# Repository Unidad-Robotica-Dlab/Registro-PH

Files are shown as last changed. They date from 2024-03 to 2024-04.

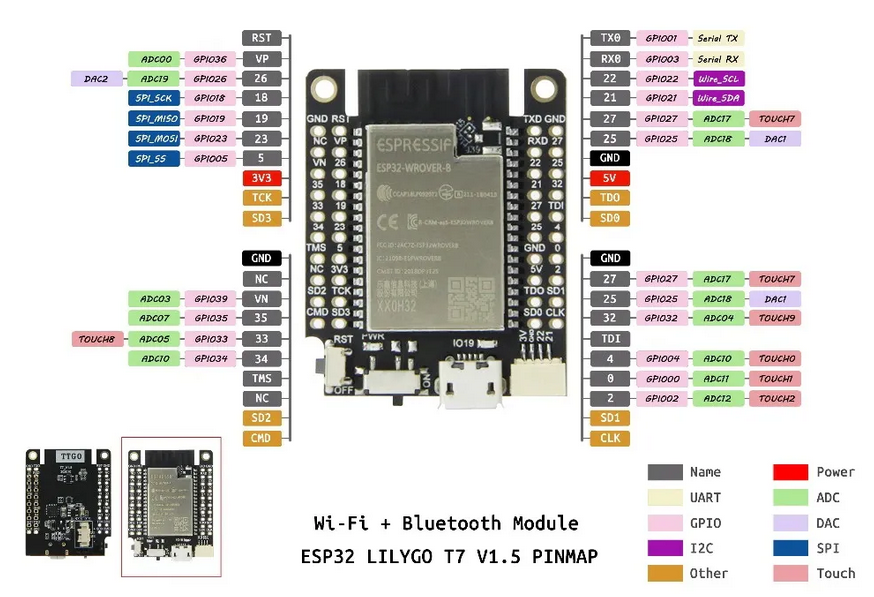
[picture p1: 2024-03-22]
Materiales/ESP32 lilygo 1.5 pinout.png

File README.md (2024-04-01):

# Proyecto: Registro-PH
## Solicitante: Simon Beard
## Contacto:sbeard@cienciavida.org 
### Laboratorio: Microbial Ecophysiology Lab Fundación Ciencia y Vida

#### Introducción:
La Maquina ElectroLab FerMac 200 es capaz de controlar el pH de una solución de forma mecánica y cuenta con un display que muestra el pH en tiempo real.

#### Requerimientos:
- Registrar el pH mediante un ESP32 y guardar los datos en una base de datos.
- Fecha de solicitud: 06/03/2024
	- Almacenar los datos de la lectura en la base de datos del ordenador.
	- Duración total de la fermentación: 4 días.
	- Tasa de muestreo por determinar.
	- Implementación de un menú interactivo.

#### Metodología:
- Leer el voltaje de salida del amplificador operacional (amplificador operacional) en la placa electrónica de la máquina, aislar el circuito mediante la adición de otro amplificador operacional en modo diferencial y leer nuevamente el voltaje de salida mediante un ESP32.
  
  1) Establecer el rango de operación en voltaje del sensor de pH.
  2) Implementar un sistema de acoplamiento con amplificador operacional.
  3) Registrar el voltaje como lectura analógica en ESP32.
  4) Almacenar los datos de la lectura en la base de datos del ordenador.

#### Software:
- [Firmware-E_RPH_v0-1](https://github.com/Unidad-Robotica-Dlab/Registro-PH/blob/main/Software/Firmware-E_RPH_v0-1/Firmware-E_RPH_v0-1.ino):
	- El ESP32 realiza la lectura del voltaje y calcula un promedio de 10 subpromedios, donde cada subpromedio es el promedio de 10 lecturas.
	- Imprime el valor de pH calculado a partir de una ecuación lineal.
- [Firmware-E_RPH_v0-2](https://github.com/Unidad-Robotica-Dlab/Registro-PH/blob/main/Software/Firmware-E_RPH_v0-2/Firmware-E_RPH_v0-2.ino):
	- Agregada la comunicacion serial con Python.
- [Software_RPH_v0-2](https://github.com/Unidad-Robotica-Dlab/Registro-PH/blob/main/Software/Software_RPH_v0-2.ipynb):
	- Interfaz de usuario con Menu para guardar los datos en un csv:
 		-  Variable: Tiempo de grabacion
   		-  Variable: Tiempo entre lecturas
- [Firmware-E_RPH_v1-0](https://github.com/Unidad-Robotica-Dlab/Registro-PH/blob/main/Software/Firmware_E_RPH_v1-0/Firmware_E_RPH_v1-0/Firmware_E_RPH_v1-0.ino)
	- Firmware 100% operativo
- [Software_RPH_v1-0](https://github.com/Unidad-Robotica-Dlab/Registro-PH/blob/main/Software/Software_RPH_v1-0.py):
	- Software 100% operativo
 		-  [Manual Tecnico del Software](https://github.com/Unidad-Robotica-Dlab/Registro-PH/blob/main/Software/Software_manual-tecnico.txt) 
   		-  [Descripción del Software](https://github.com/Unidad-Robotica-Dlab/Registro-PH/blob/main/Software/Software_descripcion.txt)

#### Notas:
- [12/02/24]
	- La máquina pH se encuentra en Robótica.
- [16/02/24]:
	- La máquina pH ha sido desarmada y se dispone de todos los implementos necesarios para medir el pH. Se han obtenido tres valores de pH diferentes: 1.68pH, 4pH y 10.1pH.
- [19/02/24]:
	- Se ha medido el voltaje de salida en el amplificador operacional de la máquina y se ha implementado un divisor de tensión.
	- Para 1.68pH, el voltaje de salida es de 17V; para 10.1pH, es de 11.1V (Voltaje de salida del amplificador operacional de la máquina [modelo: OPA602AP]).
	- Después del divisor de tensión, para 1.68pH, el voltaje es de 2.83V; para 10.1pH, es de 1.85V.
	- Los valores leídos analógicamente son 402 para 1.68pH y 261 para 10.1pH.
	- Ecuación de la recta: y = -0.0597x + 25.685.
- [21/02/24]:
	- Se ha eliminado el divisor de tensión y se ha agregado un amplificador operacional en modo diferencial para aislar los circuitos.
	- Para 1.68pH, el voltaje de salida es de 17V; para 10.1pH, es de 11.1V (Voltaje de salida del amplificador operacional de la máquina [modelo: OPA602AP]).
	- Después de agregar el amplificador operacional, para 1.68pH, el voltaje es de 2.16V; para 10.1pH, es de 1.58V.
	- Los valores leídos analógicamente son 302 para 1.68pH y 227 para 10.1pH.
	- Ecuación de la recta: y = -0.11226x + 35.58453.

- [11/03/24]:
	- Cotización y diseño del soporte del dispositivo en Inkscape.

- [19/03/24]:
	- Perillas AKHALI y ACID regulan el set point del rango de pH a leer. Para mover el setpoint se deja el encoder en SET
	- Perillas SLOPE and CAL regulan la pendiente y el intercepto. SLOPE se usa para pH 4 y  CAL para pH 7
 	- Verificar si al mover SLOPE and CAL modifica el valor del voltaje
    
- [21/03/24]:
	- Agregar menu de calibracion. Donde se calibre la maquina , luego ingrese el pH bajo (4.01) en el menu, luego se calibre la maquina con el pH alto y se ingrese el pH alto en el menu (7.01)
	- Con esos valores del pH, calcular ec de la recta. De esta forma pasamos a realizar la grabacion de datos

 - [27/03/24]:
	- Reducir ruido promediando los 10 valores.
 	- Preguntar primero por "pH 7" y luego por "pH 4".
   	- Intervalo minimo: 1min
	- Agregar submenu calibracion:
 		- Calibracion Nueva
   		- Cargar ultima Calibracion
     	- Agregar menu Ajustar Calibracion. (Esta calibracion ajustara directamente el intercepto de la ec. de la recta, es decir: "b")
      -  Mejorar el "Presione q para salir" , ya que se muestra encima del print.

 - [01/04/24]:
	- Resumen de programa y manual tecnico de uso .

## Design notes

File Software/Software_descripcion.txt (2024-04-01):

El programa es una aplicación para interactuar con un dispositivo Arduino que realiza mediciones de pH. Aquí está un resumen del funcionamiento:

    Selección del puerto serial:
        El programa muestra una lista de puertos seriales disponibles y permite al usuario seleccionar uno.

    Función para interrupcion:
        Esta función permite al usuario hacer la interrupcion al programa, con la opción de presionar 'q' para salir del bucle principal.

    Función principal (main):
        La función principal establece la comunicación con el dispositivo Arduino a través del puerto serial seleccionado.
        Muestra un menú que permite al usuario:
            Iniciar una calibración o cargar una calibración previamente guardada.
            Iniciar la grabación de datos.
            Salir del programa.
        Durante la calibración:
            El usuario puede ingresar los valores de pH conocidos (pH 7 y pH 4) para calibrar el sensor de pH conectado al Arduino.
            Los datos de la calibración se guardan en un archivo CSV.
        Durante la grabación de datos:
            El usuario puede especificar un intervalo de tiempo entre lecturas de datos de pH.
            El programa inicia la lectura de datos desde el Arduino, convierte los valores leídos en pH utilizando la calibración previamente realizada, y guarda los datos en un archivo CSV.
            La grabación de datos continúa hasta que el usuario decide detenerla o hasta que se produce una interrupción.
        El programa ofrece manejo de excepciones para detenerlo de forma ordenada si el usuario lo solicita.

    Funciones adicionales:
        Hay funciones para manejar la entrada del usuario, la selección del puerto serial, y la lectura y escritura de archivos CSV.

En resumen, este programa controla la calibración y la grabación de datos de un dispositivo de medición de pH conectado a un Arduino, proporcionando una interfaz de usuario para realizar estas acciones de manera fácil y ordenada.

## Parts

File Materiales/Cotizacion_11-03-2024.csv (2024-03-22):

Nombre | Link | Precio | Cantidad
ESP32 TTGO T7 Mini32 V1.5 | https://afel.cl/producto/placa-esp32-ttgo-t7-mini32-v1-5/?hsa_acc=1808722794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 | 16000 | 2
Conector DB15 | https://articulo.mercadolibre.cl/MLC-987675008-conector-terminal-db15-da15-dsub-macho-con-cubierta-max--_JM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 | 3000 | 1
Conector DB15 hembra | https://articulo.mercadolibre.cl/MLC-987604687-conector-terminal-db15-da15-dsub-hembra-con-cubierta-max--_JM | 3000 | 1
PCB 70x50mm | https://afel.cl/producto/placa-pcb-perforada-doble-capa-5x7cm/ | 1500 | 2
AMP-OP UA741CP | https://altronics.cl/ic-lm741 | 350 | 3
Pack Lm741 | https://articulo.mercadolibre.cl/MLC-534622588-pack-5pcs-amplificador-operacional-ua741cn-lm741-ao-max--_JM | 3000 | 1
KIT RESISTENCIAS 1/4W | https://afel.cl/producto/kit-600-resistencias-1-4w-30-valores/?hsa_acc=1808722794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 | 5000 | 1
Caja ABS 90x63x32mm | https://www.victronics.cl/caja-abs-90x63x32mm-negra-multiuso/ | 3000 | 1
Soldadura 0.7mm | https://www.casaroyal.cl/--soldadura-golden-0-7mm-60-40-250grs/p | 14000 | 1
Tester | https://diartek.cl/multitester-digital-1000vdc-750vac-10a-bk-9205b?gad_source=1 | 12700 | 1
Porta Cautin | https://www.casaroyal.cl/proskit-soporte-cautin-/p | 5000 | 1
Total |  | 62750

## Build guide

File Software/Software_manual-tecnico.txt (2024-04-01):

Manual Técnico de Uso
Introducción:

El siguiente manual técnico proporciona una guía detallada sobre el uso del programa para interactuar con un dispositivo Arduino que realiza mediciones de pH. El programa está diseñado para realizar calibraciones del sensor de pH y para grabar datos de manera continua.
Requisitos del Sistema:

    Hardware:
        Computadora con puertos USB disponibles.
        Dispositivo Arduino con un sensor de pH conectado.
        Cable USB para conectar el Arduino a la computadora.
    Software:
        Sistema operativo compatible con Python (Windows, Linux, macOS).
        Python 3.x instalado en la computadora.
        Bibliotecas Python: matplotlib, csv, datetime, serial, pandas.

Instalación de Dependencias:

    Python:
        Descargue e instale Python desde el sitio web oficial: Python.org.
    Bibliotecas Python:
        Abra la terminal o símbolo del sistema.
        Ejecute el siguiente comando para instalar las bibliotecas requeridas:

        pip install matplotlib pandas
        pip install pyserial

Configuración:

    Conexión del Dispositivo Arduino:
        Conecte el Arduino a un puerto USB disponible en su computadora utilizando el cable USB.
        Asegúrese de que el sensor de pH esté conectado correctamente al Arduino.
    Selección del Puerto Serial:
        Ejecute el programa y siga las instrucciones para seleccionar el puerto serial al que está conectado el Arduino.

Uso del Programa:

    Ejecución del Programa:
        Abra una terminal o símbolo del sistema.
        Navegue al directorio donde se encuentra el archivo del programa.
        Ejecute el programa utilizando el comando:

        python Software_RPH_v1-0.py

    Calibración:
        Elija la opción de "Iniciar Calibración" en el menú principal.
        Siga las instrucciones para ingresar los valores de pH conocidos (pH 7 y pH 4) cuando se le solicite.
        Los datos de calibración se guardarán en un archivo CSV para su uso futuro.
    Grabación de Datos:
        Seleccione la opción de "Iniciar Grabación de Datos" en el menú principal.
        Especifique el intervalo de tiempo entre las lecturas de datos de pH.
        El programa iniciará la grabación de datos y guardará los resultados en un archivo CSV con un nombre personalizado.
    Finalización del Programa:
        En cualquier momento, puede seleccionar la opción de "Salir" en el menú principal para cerrar el programa de forma ordenada.
        Asegúrese de detener la grabación de datos antes de salir del programa para evitar la pérdida de información.

Notas Adicionales:

    El programa ofrece manejo de errores y excepciones para garantizar una experiencia de usuario fluida y segura.
    Se recomienda realizar una calibración inicial antes de comenzar a grabar datos para obtener mediciones precisas de pH.
    Los archivos CSV generados pueden ser abiertos y analizados utilizando software compatible con este formato, como Microsoft Excel o Google Sheets.

Este manual técnico proporciona una visión general de los pasos necesarios para utilizar el programa de manera efectiva y maximizar su funcionalidad para realizar mediciones de pH con un dispositivo Arduino.

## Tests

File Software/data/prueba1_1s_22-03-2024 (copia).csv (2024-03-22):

tiempo | data
16:29:35 | 7.12
16:29:36 | 7.01
16:29:37 | 6.79
16:29:38 | 7.01
16:29:39 | 7.12
16:29:40 | 7.12
16:29:41 | 7.01
16:29:42 | 6.79
16:29:43 | 6.79
16:29:44 | 6.79
16:29:45 | 7.01
16:29:46 | 7.01
16:29:47 | 7.12
16:29:48 | 7.12
16:29:49 | 7.12
16:29:50 | 6.90
16:29:51 | 6.90
16:29:52 | 6.79
16:29:53 | 6.79
16:29:54 | 7.01
16:29:55 | 7.12
16:29:56 | 7.12
16:29:57 | 6.90
16:29:58 | 6.79
16:29:59 | 6.79
16:30:00 | 6.90
16:30:01 | 7.01
16:30:02 | 7.12
16:30:03 | 7.01
16:30:04 | 6.90
16:30:05 | 6.79
16:30:06 | 6.90
16:30:07 | 7.01
16:30:08 | 7.12
16:30:09 | 6.90
16:30:10 | 6.79
16:30:11 | 6.90
16:30:12 | 7.12
16:30:13 | 7.12
16:30:14 | 6.90
16:30:15 | 6.79
16:30:16 | 6.90
16:30:17 | 7.01
16:30:18 | 7.12
16:30:19 | 6.90
16:30:20 | 6.79
16:30:21 | 6.90
16:30:22 | 7.01
16:30:23 | 7.12
16:30:24 | 6.79
16:30:25 | 6.90
16:30:26 | 7.12
16:30:27 | 7.12
16:30:28 | 6.90
16:30:29 | 6.79
16:30:30 | 7.01
16:30:31 | 7.12
16:30:32 | 7.12
16:30:33 | 6.90
16:30:34 | 6.79
16:30:35 | 6.90
16:30:36 | 7.12
16:30:37 | 7.01
16:30:38 | 7.12
16:30:39 | 6.79
16:30:40 | 6.79
16:30:41 | 6.90
16:30:42 | 7.12
16:30:43 | 7.12
16:30:44 | 6.90
16:30:45 | 6.79
16:30:46 | 6.90
16:30:47 | 7.12
16:30:48 | 7.01
16:30:49 | 6.79
16:30:50 | 6.90
16:30:51 | 7.01
16:30:52 | 6.90
16:30:53 | 6.79
16:30:54 | 7.01
16:30:55 | 7.12
16:30:56 | 6.90
16:30:57 | 6.79
16:30:58 | 7.01
16:30:59 | 7.12
16:31:00 | 7.01
16:31:01 | 6.90
16:31:02 | 6.79
16:31:03 | 7.01
16:31:04 | 7.12
16:31:05 | 7.12
16:31:06 | 7.01
16:31:07 | 6.68
16:31:08 | 6.79
16:31:09 | 7.01
16:31:10 | 7.01
16:31:11 | 7.01
16:31:12 | 7.01
16:31:13 | 6.79
16:31:14 | 6.79
16:31:15 | 6.90
16:31:16 | 7.12
16:31:17 | 7.01
16:31:18 | 7.12
16:31:19 | 7.01
16:31:20 | 6.79
16:31:21 | 6.79
16:31:22 | 6.79
16:31:23 | 7.01
16:31:24 | 7.12
16:31:25 | 7.01
16:31:26 | 7.12
16:31:27 | 7.01
16:31:28 | 6.79
16:31:29 | 6.79
16:31:30 | 6.79
16:31:31 | 7.01
16:31:32 | 7.12
16:31:33 | 7.12
16:31:34 | 7.01
16:31:35 | 6.68
16:31:36 | 6.79
16:31:37 | 6.90
16:31:38 | 7.01
16:31:39 | 7.12
16:31:40 | 7.12
16:31:41 | 6.90
16:31:42 | 6.79
16:31:43 | 6.79
16:31:44 | 7.12
16:31:45 | 7.01
16:31:46 | 7.01
16:31:47 | 6.79
16:31:48 | 6.79
16:31:49 | 6.90
16:31:50 | 7.12
16:31:51 | 7.01
16:31:52 | 6.90
16:31:53 | 6.79
16:31:54 | 6.79
16:31:55 | 6.90
16:31:56 | 7.12
16:31:57 | 6.79
16:31:58 | 6.79
16:31:59 | 6.68
16:32:00 | 7.01
16:32:01 | 7.01
16:32:02 | 7.01
16:32:03 | 6.79
16:32:04 | 6.79
16:32:05 | 6.90
16:32:06 | 7.12
16:32:07 | 7.12
16:32:08 | 6.79
16:32:09 | 6.79
16:32:10 | 6.90
16:32:11 | 7.12
16:32:12 | 7.12
16:32:13 | 6.79
16:32:14 | 6.79
16:32:15 | 7.01
16:32:16 | 7.01
16:32:17 | 6.90
16:32:18 | 6.79
16:32:19 | 6.90
16:32:20 | 7.01
16:32:21 | 7.01
16:32:22 | 6.79
16:32:23 | 6.90
16:32:24 | 7.01
16:32:25 | 7.12
16:32:26 | 6.90
16:32:27 | 6.68
16:32:28 | 6.79
16:32:29 | 7.01
16:32:30 | 7.01
16:32:31 | 7.12
16:32:32 | 6.90
16:32:33 | 6.68
16:32:34 | 6.79
16:32:35 | 6.90
16:32:36 | 7.01
16:32:37 | 7.12
16:32:38 | 7.01
16:32:39 | 6.79
16:32:40 | 6.79
16:32:41 | 6.79
16:32:42 | 7.01
16:32:43 | 7.12
16:32:44 | 7.01
16:32:45 | 6.79
16:32:46 | 6.79
16:32:47 | 6.79
16:32:48 | 7.01
16:32:49 | 7.01
16:32:50 | 6.90
16:32:51 | 6.57
16:32:52 | 6.79
16:32:53 | 6.90
16:32:54 | 7.12
16:32:55 | 7.01
16:32:56 | 6.90
16:32:57 | 6.79
16:32:58 | 6.79
16:32:59 | 6.90
16:33:00 | 7.01
16:33:01 | 7.01
16:33:02 | 7.12
16:33:03 | 6.90
16:33:04 | 6.90
16:33:05 | 6.79
16:33:06 | 6.79
16:33:07 | 6.90
16:33:08 | 7.01
16:33:09 | 7.01
16:33:10 | 6.68
16:33:11 | 6.68
16:33:12 | 7.01
16:33:13 | 7.12
16:33:14 | 6.90
16:33:15 | 6.79
16:33:16 | 7.01
16:33:17 | 7.12
16:33:18 | 6.79
16:33:19 | 6.79
16:33:20 | 7.01
16:33:21 | 7.01
16:33:22 | 6.79
16:33:23 | 6.68
16:33:24 | 7.01
16:33:25 | 7.01
16:33:26 | 6.90
16:33:27 | 6.79
16:33:28 | 6.90
16:33:29 | 7.01
16:33:30 | 7.01
16:33:31 | 6.79
16:33:32 | 6.79
16:33:33 | 6.90
16:33:34 | 7.01
16:33:35 | 7.12
16:33:36 | 6.79
16:33:37 | 6.79
16:33:38 | 6.79
16:33:39 | 7.01
16:33:40 | 7.01
16:33:41 | 7.12
16:33:42 | 6.90
16:33:43 | 6.79
16:33:44 | 6.79
16:33:45 | 7.01
16:33:46 | 7.12
16:33:47 | 6.79
16:33:48 | 6.79
16:33:49 | 6.79
16:33:50 | 7.01
16:33:51 | 7.12
16:33:52 | 6.79
16:33:53 | 6.79
16:33:54 | 7.01
16:33:55 | 7.01
16:33:56 | 6.90
16:33:57 | 6.79
16:33:58 | 7.01
16:33:59 | 7.01
16:34:00 | 6.90
16:34:01 | 6.68
16:34:02 | 6.90
16:34:03 | 7.01
16:34:04 | 6.79
16:34:05 | 6.68
16:34:06 | 7.01
16:34:07 | 7.12
16:34:08 | 6.79
16:34:09 | 6.68
16:34:10 | 7.01
16:34:11 | 7.01
16:34:12 | 6.79
16:34:13 | 6.79
16:34:14 | 6.90
16:34:15 | 7.01
16:34:16 | 7.12
16:34:17 | 6.79
16:34:18 | 6.79
16:34:19 | 6.90
16:34:20 | 7.01
16:34:21 | 7.01
16:34:22 | 7.01
16:34:23 | 7.01
16:34:24 | 6.68
16:34:25 | 6.90
16:34:26 | 7.12
16:34:27 | 7.01
16:34:28 | 6.79
16:34:29 | 6.79
16:34:30 | 7.01
16:34:31 | 7.01
16:34:32 | 6.79
16:34:33 | 6.68
16:34:34 | 7.01
16:34:35 | 7.01
16:34:36 | 6.79
16:34:37 | 6.79
16:34:38 | 7.01
16:34:39 | 7.12
16:34:40 | 6.79
16:34:41 | 6.79
16:34:42 | 6.79
16:34:43 | 7.12
16:34:44 | 7.01
16:34:45 | 6.79
16:34:46 | 6.79
16:34:47 | 7.01
16:34:48 | 7.12
16:34:49 | 7.01
16:34:50 | 6.79
16:34:51 | 6.79
16:34:52 | 7.01
16:34:53 | 7.12
16:34:54 | 6.90
16:34:55 | 6.79
16:34:56 | 6.79
16:34:57 | 7.01
16:34:58 | 7.12
16:34:59 | 6.79
16:35:00 | 6.79
16:35:01 | 6.90
16:35:02 | 7.01
16:35:03 | 6.90
16:35:04 | 6.79
16:35:05 | 6.90
16:35:06 | 7.01
16:35:07 | 7.01
16:35:08 | 6.79
16:35:09 | 6.90
16:35:10 | 7.12
16:35:11 | 7.01
16:35:12 | 6.79
16:35:13 | 6.79
16:35:14 | 6.90
16:35:15 | 7.12
16:35:16 | 7.12
16:35:17 | 6.90
16:35:18 | 6.79
16:35:19 | 6.79
16:35:20 | 6.90
16:35:21 | 6.90
16:35:22 | 7.12
16:35:23 | 6.90
16:35:24 | 6.79
16:35:25 | 6.79
16:35:26 | 7.01
16:35:27 | 7.01
16:35:28 | 7.01
16:35:29 | 6.79
16:35:30 | 6.79
16:35:31 | 6.90
16:35:32 | 7.01
16:35:33 | 7.01
16:35:34 | 6.79
16:35:35 | 6.90
16:35:36 | 7.01
16:35:37 | 7.01
16:35:38 | 6.90
16:35:39 | 6.90
16:35:40 | 6.90
16:35:41 | 7.12
16:35:42 | 7.01
16:35:43 | 6.90
16:35:44 | 6.79
16:35:45 | 6.90
16:35:46 | 7.01
16:35:47 | 6.90
16:35:48 | 6.79
16:35:49 | 7.01
16:35:50 | 7.01
16:35:51 | 6.90
16:35:52 | 6.79
16:35:53 | 7.01
16:35:54 | 7.01
16:35:55 | 7.01
16:35:56 | 6.79
16:35:57 | 6.90
16:35:58 | 7.01
16:35:59 | 7.01
16:36:00 | 6.79
16:36:01 | 6.79
16:36:02 | 7.01
16:36:03 | 7.12
16:36:04 | 6.90
16:36:05 | 6.79
16:36:06 | 6.90
16:36:07 | 7.01
16:36:08 | 7.01
16:36:09 | 6.90
16:36:10 | 6.90
16:36:11 | 7.01
16:36:12 | 7.01
16:36:13 | 6.79
16:36:14 | 6.79
16:36:15 | 7.12
16:36:16 | 7.01
16:36:17 | 6.79
16:36:18 | 6.79
16:36:19 | 6.90
16:36:20 | 7.01
16:36:21 | 7.01
16:36:22 | 6.79
16:36:23 | 6.90
16:36:24 | 7.01
16:36:25 | 7.01
16:36:26 | 6.90
16:36:27 | 6.79
16:36:28 | 6.79
16:36:29 | 7.01
16:36:30 | 7.01
16:36:31 | 6.79
16:36:32 | 6.79
16:36:33 | 6.90
16:36:34 | 7.01
16:36:35 | 6.90
16:36:36 | 6.68
16:36:37 | 7.01
16:36:38 | 7.12
16:36:39 | 6.79
16:36:40 | 6.79
16:36:41 | 7.12
16:36:42 | 7.01
16:36:43 | 6.79
16:36:44 | 6.79
16:36:45 | 7.01
16:36:46 | 7.01
16:36:47 | 6.79
16:36:48 | 6.79
16:36:49 | 7.12
16:36:50 | 6.90
16:36:51 | 6.79
16:36:52 | 7.01
16:36:53 | 7.12
16:36:54 | 6.79
16:36:55 | 6.79
16:36:56 | 7.01
16:36:57 | 7.01
16:36:58 | 6.79
16:36:59 | 6.79
16:37:00 | 7.01
16:37:01 | 7.12
16:37:02 | 6.79
16:37:03 | 6.79
16:37:04 | 7.01
16:37:05 | 7.01
16:37:06 | 7.12
16:37:07 | 6.90
16:37:08 | 6.79
16:37:09 | 6.79
16:37:10 | 7.01
16:37:11 | 7.12
16:37:12 | 7.12
16:37:13 | 6.90
16:37:14 | 6.79
16:37:15 | 6.79
16:37:16 | 7.01
16:37:17 | 7.01
16:37:18 | 7.01
16:37:19 | 6.79
16:37:20 | 6.90
16:37:21 | 6.79
16:37:22 | 7.01
16:37:23 | 7.12
16:37:24 | 6.90
16:37:25 | 6.79
16:37:26 | 6.90
16:37:27 | 7.01
16:37:28 | 6.90
16:37:29 | 6.79
16:37:30 | 6.90
16:37:31 | 7.01
16:37:32 | 6.90
16:37:33 | 6.79
16:37:34 | 6.90
16:37:35 | 7.01
16:37:36 | 6.90
16:37:37 | 6.79
16:37:38 | 6.90
16:37:39 | 7.01
16:37:40 | 6.79
16:37:41 | 6.79
16:37:42 | 6.90
16:37:43 | 7.01
16:37:44 | 6.79
16:37:45 | 6.79
16:37:46 | 6.90
16:37:47 | 7.01
16:37:48 | 6.90
16:37:49 | 6.79
16:37:50 | 6.90
16:37:51 | 7.01
16:37:52 | 7.01
16:37:53 | 6.79
16:37:54 | 6.79
16:37:55 | 6.90
16:37:56 | 7.01
16:37:57 | 7.01
16:37:58 | 6.79
16:37:59 | 6.79
16:38:00 | 6.90
16:38:01 | 7.12
16:38:02 | 7.12
16:38:03 | 6.79
16:38:04 | 6.68
16:38:05 | 6.90
16:38:06 | 6.79
16:38:07 | 7.01
16:38:08 | 6.79
16:38:09 | 6.79
16:38:10 | 7.01
16:38:11 | 7.01
16:38:12 | 6.79
16:38:13 | 6.79
16:38:14 | 7.01
16:38:15 | 7.01
16:38:16 | 6.79
16:38:17 | 6.79
16:38:18 | 7.12
16:38:19 | 7.01
16:38:20 | 6.79
16:38:21 | 6.90
16:38:22 | 7.01
16:38:23 | 6.90
16:38:24 | 6.79
16:38:25 | 7.01
16:38:26 | 7.01
16:38:27 | 6.79
16:38:28 | 6.68
16:38:29 | 7.01
16:38:30 | 7.01
16:38:31 | 6.90
16:38:32 | 6.79
16:38:33 | 6.90
16:38:34 | 7.12
16:38:35 | 7.01
16:38:36 | 6.90
16:38:37 | 6.79
16:38:38 | 6.90
16:38:39 | 7.12
16:38:40 | 7.01
16:38:41 | 6.68
16:38:42 | 6.68
16:38:43 | 6.90
16:38:44 | 7.01
16:38:45 | 7.01
16:38:46 | 6.79
16:38:47 | 6.79
16:38:48 | 7.01
16:38:49 | 7.12
16:38:50 | 6.79
16:38:51 | 6.79
16:38:52 | 7.01
16:38:53 | 7.01
16:38:54 | 6.90
16:38:55 | 6.79
16:38:56 | 6.90
16:38:57 | 7.12
16:38:58 | 7.12
16:38:59 | 6.90
16:39:00 | 6.79
16:39:01 | 6.90
16:39:02 | 7.12
16:39:03 | 7.01
16:39:04 | 6.79
16:39:05 | 6.79
16:39:06 | 7.01
16:39:07 | 6.90
16:39:08 | 6.90
16:39:09 | 6.79
16:39:10 | 6.90
16:39:11 | 7.12
16:39:12 | 7.01
16:39:13 | 6.79
16:39:14 | 6.68
16:39:15 | 7.12
16:39:16 | 7.12
16:39:17 | 6.90
16:39:18 | 6.79
16:39:19 | 6.90
16:39:20 | 7.01
16:39:21 | 7.01
16:39:22 | 6.79
16:39:23 | 6.79
16:39:24 | 7.01
16:39:25 | 7.01
16:39:26 | 6.79
16:39:27 | 6.79
16:39:28 | 6.90
16:39:29 | 7.01
16:39:30 | 7.01
16:39:31 | 6.79
16:39:32 | 6.79
16:39:33 | 7.01
16:39:34 | 7.01
16:39:35 | 6.79
16:39:36 | 6.79
16:39:37 | 6.90
16:39:38 | 7.12
16:39:39 | 6.90
16:39:40 | 6.79
16:39:41 | 6.68
16:39:42 | 7.01
16:39:43 | 7.01
16:39:44 | 6.90
16:39:45 | 6.79
16:39:46 | 6.90
16:39:47 | 7.12
16:39:48 | 7.01
16:39:49 | 6.79
16:39:50 | 6.90
16:39:51 | 7.01
16:39:52 | 7.12
16:39:53 | 6.79
16:39:54 | 6.79
16:39:55 | 7.01
16:39:56 | 7.01
16:39:57 | 6.79
16:39:58 | 6.68
16:39:59 | 6.90
16:40:00 | 7.01
16:40:01 | 6.79
16:40:02 | 6.79
16:40:03 | 6.79
16:40:04 | 7.01
16:40:05 | 7.12
16:40:06 | 6.90
16:40:07 | 6.79
16:40:08 | 6.90
16:40:09 | 7.01
16:40:10 | 7.01
16:40:11 | 6.79
16:40:12 | 6.79
16:40:13 | 7.01
16:40:14 | 7.01
16:40:15 | 7.01
16:40:16 | 6.79
16:40:17 | 6.79
16:40:18 | 7.01
16:40:19 | 7.01
16:40:20 | 6.90
16:40:21 | 6.90
16:40:22 | 6.79
16:40:23 | 6.90
16:40:24 | 7.01
16:40:25 | 7.12
16:40:26 | 6.79
16:40:27 | 6.79
16:40:28 | 6.79
16:40:29 | 6.79
16:40:30 | 7.01
16:40:31 | 7.01
16:40:32 | 7.01
16:40:33 | 6.79
16:40:34 | 6.79
16:40:35 | 6.68
16:40:36 | 7.01
16:40:37 | 7.01
16:40:38 | 7.12
16:40:39 | 6.79
16:40:40 | 6.79
16:40:41 | 6.79
16:40:42 | 7.01
16:40:43 | 7.01
16:40:44 | 6.79
16:40:45 | 6.68
16:40:46 | 7.12
16:40:47 | 7.01
16:40:48 | 6.79
16:40:49 | 6.79
16:40:50 | 6.90
16:40:51 | 7.01
16:40:53 | 6.90
16:40:54 | 6.79
16:40:55 | 7.01
16:40:56 | 7.01
16:40:57 | 6.90
16:40:58 | 6.68
16:40:59 | 7.01
16:41:00 | 7.01
16:41:01 | 6.79
16:41:02 | 6.68
16:41:03 | 7.01
16:41:04 | 7.01
16:41:05 | 6.90
16:41:06 | 6.79
16:41:07 | 6.79
16:41:08 | 7.01
16:41:09 | 7.12
16:41:10 | 6.90
16:41:11 | 6.79
16:41:12 | 6.79
16:41:13 | 7.01
16:41:14 | 7.01
16:41:15 | 7.01
16:41:16 | 6.79
16:41:17 | 6.79
16:41:18 | 6.90
16:41:19 | 7.01
16:41:20 | 7.01
16:41:21 | 6.79
16:41:22 | 6.79
16:41:23 | 6.79
16:41:24 | 7.01
16:41:25 | 7.12
16:41:26 | 6.90
16:41:27 | 6.79
16:41:28 | 6.90
16:41:29 | 7.12
16:41:30 | 6.90
16:41:31 | 6.79
16:41:32 | 6.79
16:41:33 | 7.23
16:41:34 | 7.01
16:41:35 | 7.01
16:41:36 | 6.79
16:41:37 | 6.79
16:41:38 | 6.90
16:41:39 | 7.01
16:41:40 | 7.01
16:41:41 | 6.90
16:41:42 | 6.79
16:41:43 | 6.68
16:41:44 | 6.90
16:41:45 | 7.01
16:41:46 | 7.12
16:41:47 | 6.90
16:41:48 | 6.79
16:41:49 | 6.68
16:41:50 | 6.90
16:41:51 | 7.01
16:41:52 | 7.01
16:41:53 | 6.79
16:41:54 | 6.79
16:41:55 | 6.79
16:41:56 | 7.12
16:41:57 | 7.01
16:41:58 | 6.79
16:41:59 | 6.68
16:42:00 | 6.90
16:42:01 | 7.01
16:42:02 | 7.01
16:42:03 | 6.79
16:42:04 | 6.79
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

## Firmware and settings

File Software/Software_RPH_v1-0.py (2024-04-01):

import time
from matplotlib import pyplot as plt
import csv
import os
import datetime
import serial
import serial.tools.list_ports
from matplotlib.ticker import NullFormatter
import threading
import sys
import pandas as pd

#########################################################################################################
def seleccionar_puerto():
    puertos_disponibles = [puerto.device for puerto in serial.tools.list_ports.comports()]

    if not puertos_disponibles:
        print("No se encontraron puertos seriales disponibles.")
        return None
    print("------------------------------------------------")
    print("SELECCIONE PUERTO SERIAL:")
    for indice, puerto in enumerate(puertos_disponibles, start=1):
        print(f"{indice}. {puerto}")

    seleccion = 0
    while True:
        try:
            seleccion = int(input("Seleccione el número del puerto a usar: "))
            print("------------------------------------------------")
            if 1 <= seleccion <= len(puertos_disponibles):
                break
            else:
                print("Seleccion incorrecta. Intente de nuevo.")
        except ValueError:
            print("Entrada inválida. Por favor, ingrese un número.")

    puerto_seleccionado = puertos_disponibles[seleccion - 1]
    return puerto_seleccionado

puerto = seleccionar_puerto()
fecha = datetime.datetime.now().strftime("%d-%m-%Y")

vector = []
##########################################################################################################
def interrupcion():
    global continuar
    print("Presione 'q' para salir")
    while True:
        entrada = input("").strip().lower()
        if entrada == 'q':
            continuar = False
            break

continuar = True

##########################################################################################################
ruta_archivo2 = './/calibracion.csv'

def main():
    m=None
    b=None
    alfa=None
    salir = False
    arduino = serial.Serial(puerto, 115200, timeout=1) #windows
    time.sleep(1) # Espera a que Arduino se inicialice
    arduino.flushInput()
    print("MENU PRINCIPAL")  
    print("Escriba el nombre del archivo a guardar (Por ejemplo: EXP1_Simon [Experimento_Autor])")
    nombre_archivo = input("Nombre del archivo: ")
    print("Estas seguro?")
    print("1. Si")
    print("2. No")
    confirmar = input("Seleccione una opción (1 o 2): ")
    print("------------------------------------------------")
    if confirmar == '1':
        while not salir:
            print("1. Iniciar Calibracion")
            print("2. Iniciar Grabacion de datos")
            print("3. Salir")
            opcionn = input("Seleccione una opción (1,2 o 3): ")

            if opcionn == '1':
                bandera = 'si'
                print("1. Iniciar nueva calibracion")
                print("2. Cargar ultima calibracion")
                opcion_cal = input("Seleccione una opción (1,2): ")
                if opcion_cal == '1':
                    print("------------------------------------------------")
                    y1 = float(input("Seleccione el pH 7: "))
                    instruccion = 'LEER\r'
                    print("Enviando a Arduino: ", instruccion)
                    time.sleep(1)
                    arduino.write(instruccion.encode('utf-8'))
                    z1 = arduino.readline().decode().strip() #7.01(y2) = 255(x2) // 4.01(y1) = 282(x1) // y=−0.1111111111111111x+35.343333333333334
                    print(z1)
                    if z1=='Ok':
                        x1 = arduino.readline().decode().strip()
                        if x1 is not None and x1 != "":
                            try:
                                x1 = float(x1)
                            except ValueError:
                                print("El string no representa un número válido:", x1)
                        else:
                            print("No se recibieron datos desde Arduino.")
                            break
                    
                    time.sleep(1)
                    y2 = float(input("Seleccione el pH 4: "))
                    instruccion = 'LEER\r'
                    print("Enviando a Arduino: ", instruccion)
                    time.sleep(1)
                    arduino.write(instruccion.encode('utf-8'))
                    z2 = arduino.readline().decode().strip() #7.01(y2) = 255(x2) // 4.01(y1) = 282(x1) // y=−0.1111111111111111x+35.343333333333334
                    print(z2)
                    if z2=='Ok':
                        x2 = arduino.readline().decode().strip()
                        if x2 is not None and x2 != "":
                            try:
                                x2 = float(x2)
                            except ValueError:
                                print("El string no representa un número válido:", x1)
                        else:
                            print("No se recibieron datos desde Arduino.")
                            break
                        
                        while True:
                            print("Estas seguro de los valores de pH ingresados?: ")
                            print("1. Si")
        
                            print("2. No") 
                            iniciar_cal = input("Seleccione una opcion (1 o 2): ")
                            if iniciar_cal =="1":
                                if x1 == x2:
                                    print("ERROR: los valores de pH ingresados son iguales")
                                    orden = 'R\r'
                                    time.sleep(1)
                                    arduino.write(orden.encode('utf-8'))
                                    salir = True
                                    break
                                else:
                                    m = (y2 - y1) / (x2 - x1) 
                                    b = y1 - m * x1
                                    time.sleep(1)
                                    print("Valores ingresados correctamente!")
                                    alfa = 0
                                    time.sleep(1)
                                    
                                    archivo_cal = open(ruta_archivo2, mode='a', newline='')
                                    escritor_cal = csv.writer(archivo_cal)
                                    escritor_cal.writerow([x1,x2,y1,y2,m,b])
                                    archivo_cal.close()
                                    break
                            if iniciar_cal =="2":
                                orden = 'R\r'
                                time.sleep(1)
                                arduino.write(orden.encode('utf-8'))
                                salir = True
                                break
                
                if opcion_cal == '2':
                    df_cal = pd.read_csv(ruta_archivo2)
                    x1= float(df_cal.columns[0])
                    x2= float(df_cal.columns[1])
                    y1= float(df_cal.columns[2])
                    y2= float(df_cal.columns[3])
                    m= float(df_cal.columns[4])
                    b= float(df_cal.columns[5])
                    print(x1,x2,y1,y2,m,b)
                    while True:
                        print("1. Ajustar calibracion")
                        opcion_ajs = input("Seleccione una opción: ")  
                        if opcion_ajs == '1':
                            y1_a = float(input("Seleccione el pH 7 ajustado: "))
                            instruccion = 'LEER\r'
                            print("Enviando a Arduino: ", instruccion)
                            time.sleep(1)
                            arduino.write(instruccion.encode('utf-8'))
                            z1_a = arduino.readline().decode().strip() #7.01(y2) = 255(x2) // 4.01(y1) = 282(x1) // y=−0.1111111111111111x+35.343333333333334
                            print(z1_a)
                            if z1_a=='Ok':
                                x1_a = arduino.readline().decode().strip()
                                if x1_a is not None and x1_a != "":
                                    try:
                                        x1_a = float(x1_a)
                                        print("el nuevo es: ",x1_a)
                                        alfa= x1-x1_a
                                        print("alfa es: " ,alfa)
                                        break
                                    except ValueError:
                                        print("El string no representa un número válido:", x1_a)
                                else:
                                    print("No se recibieron datos desde Arduino.")
                                    break
                        else:
                            print("ERROR: Debe realizar el ajuste")
            
            if opcionn == '2':

                print("------------------------------------------------")
                t_lectura = int(input("Seleccione un intervalo de tiempo (segs) entre lecturas: "))
                ruta_archivo = './/'+nombre_archivo+'_'+str(t_lectura)+'s_'+fecha+'.csv'
                
                if m == None:
                    print('ERROR: Primero debe realizar la calibración')
                    orden = 'R\r'
                    time.sleep(1)
                    arduino.write(orden.encode('utf-8'))
                    salir = True
                    break
                while True:
                    print("Quiere iniciar el programa?")
                    print("1. Si")
                    print("2. No") 
                    iniciar = input("Seleccione una opcion (1 o 2): ")
                    if iniciar =="1":
                        print("------------------------------------------------")
                        print("iniciando el programa...")
                        instruccion = 'LEER\r'
                        print("Enviando a Arduino: ", instruccion)
                        time.sleep(1)
                        arduino.write(instruccion.encode('utf-8'))
                        print("------------------------------------------------")
                        z3 = arduino.readline().decode().strip() #7.01(y2) = 255(x2) // 4.01(y1) = 282(x1) // y=−0.1111111111111111x+35.343333333333334
                        print(z3)
                        if z3 =="Ok":
                            time.sleep(1)
                            print("Hora,data")
                            data_count = 0
                            thread_entrada = threading.Thread(target=interrupcion)
                            thread_entrada.start()
                            try:
                                while True:
                                    archivo_csv = open(ruta_archivo, mode='a', newline='')
                                    escritor_csv = csv.writer(archivo_csv)
                                    escritor_csv.writerow(["tiempo","data"])
    
                                    try:
                                        while continuar:
                                            arduino.write(instruccion.encode('utf-8'))
                                            z4 = arduino.readline().decode().strip()
                                            if z4=='Ok':
                                                data = arduino.readline().decode().strip()
                                                if data is not None and data != "":
                                                    data_count = data_count+1
        
                                                    data_pH = m*(float(data)+alfa)+b 
                                                    data_pH = "{:.2f}".format(data_pH)
                                                    tiempo_actual = time.strftime('%H:%M:%S') 
                                                    archivo_csv = open(ruta_archivo, mode='a', newline='')
                                                    escritor_csv = csv.writer(archivo_csv)
                                                    escritor_csv.writerow([tiempo_actual,data_pH])
                                                    archivo_csv.close()
                                                    print(f"{tiempo_actual},{data_pH} pH\r", end="")
                                                    time.sleep(t_lectura)


                                    except KeyboardInterrupt:
                                        print("Programa detenido por el usuario.")
                                    thread_entrada.join()

                                    break
                                print("------------------------------------------------")
                                time.sleep(1)
                                print("Saliendo, espere un momento...")
                                time.sleep(1)
                                print(".")
                                time.sleep(1)
                                print(".")
                                time.sleep(1)
                                print("Programa terminado")
                                time.sleep(2)
                                orden = 'R\r'
                                time.sleep(1)
                                arduino.write(orden.encode('utf-8'))
                                salir = True
                                break
        
        
                            except KeyboardInterrupt:
                                print("Programa detenido por el usuario.")
                                    
                                                   
                    elif iniciar =="2":
                        print("------------------------------------------------")
                        break
                    else:
                        print("Error")
    
    
            elif opcionn == '3':
                print("Terminado")
                arduino.close()
                time.sleep(3)
                salir = True
                

    if confirmar == '2':
        print("Reiniciando...")
        time.sleep(3)
        main()
if __name__ == "__main__":
    main()

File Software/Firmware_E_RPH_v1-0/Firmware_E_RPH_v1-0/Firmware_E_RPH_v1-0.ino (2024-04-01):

size_t numMuestras;
//ADC
#define BUFFER_SIZE 1024
int lecturas[BUFFER_SIZE];
int valores[10]; 
float vectorpH[10];
////////////////////////////
const int ADC_Carga = 35; 
int promedio;
int numValores = 0; 
int a=0;
int j=1;
int suma = 0;

void setup() {
  Serial.begin(115200); 
  adcAttachPin(ADC_Carga);
  analogReadResolution(9);
  analogSetPinAttenuation(ADC_Carga,ADC_11db);
  analogSetWidth(12);
  analogSetClockDiv(1);
  if (numMuestras > BUFFER_SIZE) {
  return;
  }

}

void loop() {

    if (Serial.available() > 0) { 
        String data = Serial.readStringUntil('\r');

          if (data == "LEER") { 
                  Serial.println("Ok");
                  for (size_t i = 0; i < 10; i++) { // Repite el parpadeo 5 veces
                    lecturas[i] = analogRead(ADC_Carga);
                    delay(100); // OTRA VARIABLE
                  }
                  for (int i = 0; i < 10; i++) {
                    suma += lecturas[i];
                              
                  }
                  promedio = suma/10;
                  Serial.println(promedio);
                  promedio = 0;
                  suma = 0;
          }
          if (data == "R") { 
            ESP.restart();
          }
          
      }
  }
  

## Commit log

2024-02-12 Amplificador operacional de la maquina ElectroLab (llega al sensor ph)
2024-02-22 Esquematico de proyecto
    [Schematic2.fzz]
2024-02-22 Esquematico Proyecto
    [Schematic.fzz]
